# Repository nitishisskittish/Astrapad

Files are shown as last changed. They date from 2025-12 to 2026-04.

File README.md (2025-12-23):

## **Astrapad**
---
A 7 key macropad with a rotary encoder, OLED screen, and 16 WS2812B LED’s. Currently runs on KMK firmware

### **Features**
---
- Two Piece 3D Printable Case
- 128x32 OLED Display
- EC11 Rotary encoder
- 16 WS2812B RGB LEDs, probably waaayyy too much, but the more the merrier I guess
- 7 Keys

### **CAD Model**
---
The case is held together by 4 M3 Bolts and heatset inserts, 1 in each corner. The bottom half of the case has a built in tilt. Originally I designed this with see-through plastic “windows” in mind, but as of now those windows have been replaced with direct holes looking into the PCB. Maybe I’ll add them later.

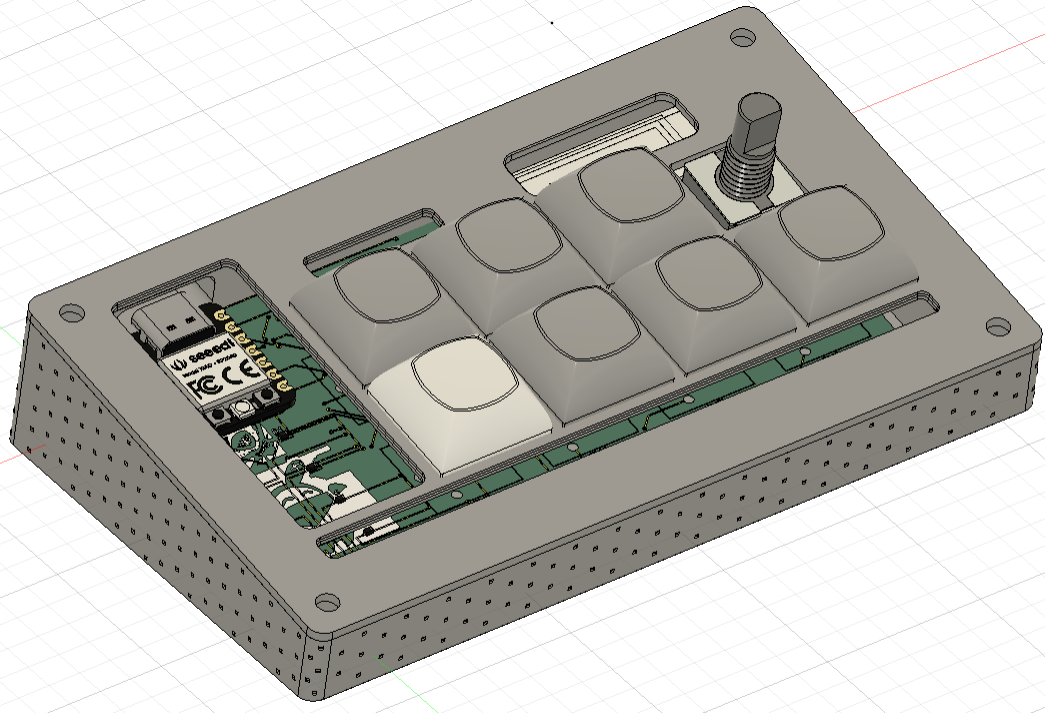
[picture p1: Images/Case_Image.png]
Case


### **PCB**
---
I made my PCB in KiCad. I got the bangboo silkscreen arts from the [Zenless Zone Zero Fandom Sticker Page](https://zenless-zone-zero.fandom.com/wiki/Stickers), and the pikachu art from [pixlecheese](https://www.pixilart.com/art/pikachu-thunderbolt-1a236168d6612c3)

- Schematic:

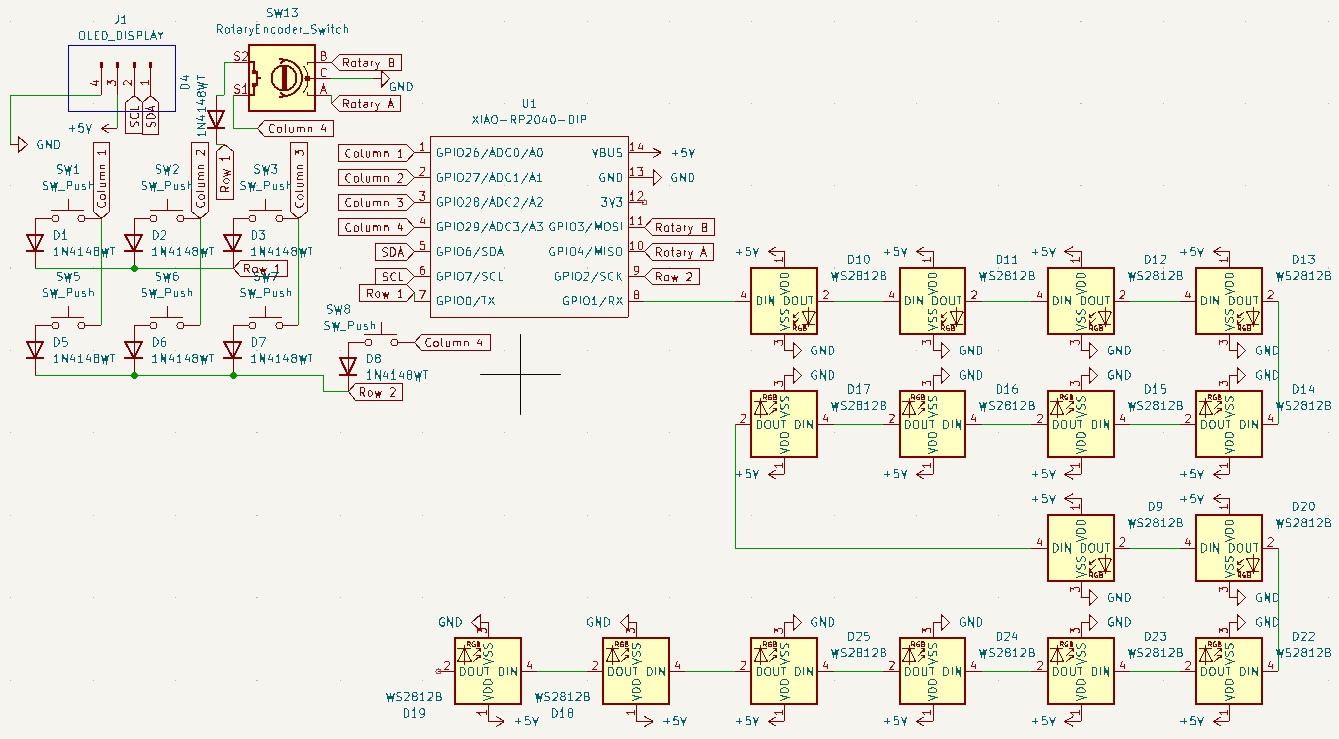
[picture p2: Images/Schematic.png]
Schematic
  
- Schematic:

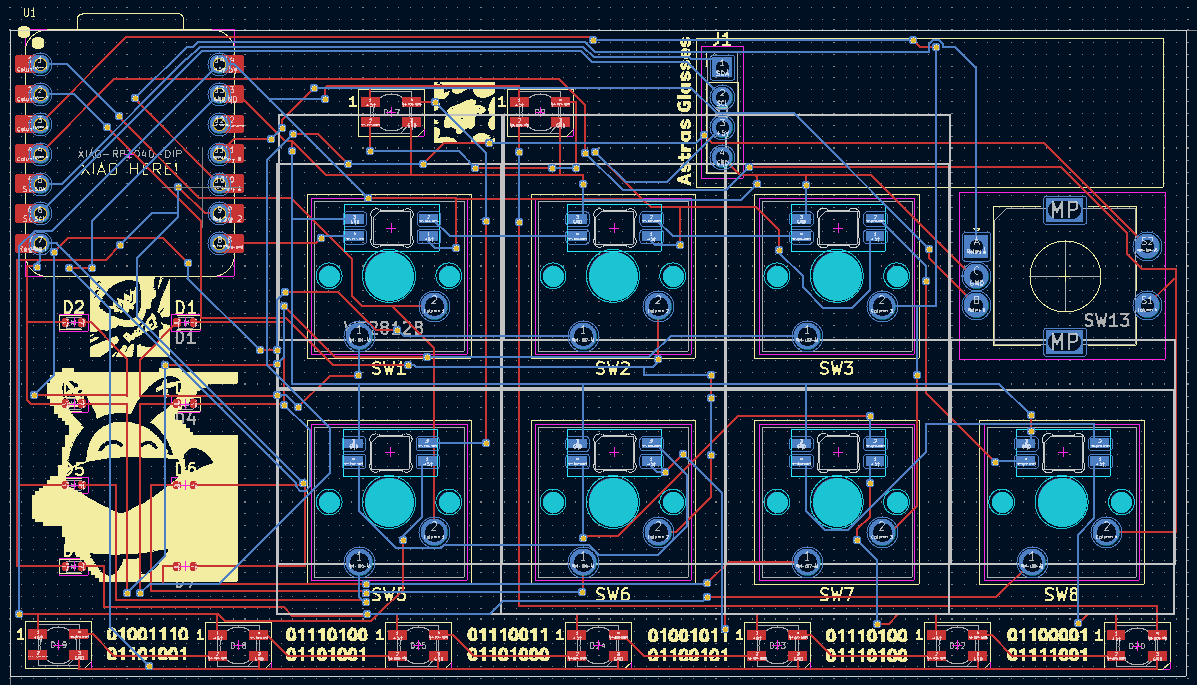
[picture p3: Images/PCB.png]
PCB
  
- My favorite part of the whole project tbh, made me feel very smart. Also if you're interested the numbers at the very bottom are binary, although it doesn’t spell out anything that interesting

### **Firmware**
---
Currently Astrapad runs on KMK, but I plan on switching to QMK later because I want to add [VIA](https://caniusevia.com/) support
- The rotary encoder changes the volume, and you can tap it to toggle mute
- The top left and top right keys skips forward or backward respectively in the playback queue
- The top middle button and bottom 3 buttons act as WASD keys, with the top middle button being the W Key
- The bottom right button is currently mapped to a custom shortcut I have on my computer that opens Spotify
- The OLED Screen displays the current volume level of whatever device the macropad is currently connected to
- I have a list of features I want to add commented in the KMK main.py file if you're interested in that
### **BOM**
---
- 1x Seeed XIAO RP2040
- 1x 0.91 inch OLED displays 
- 1x EC11 rotary encoders
- 1x Case (2 3D printed parts)
- 1x 3D printed EC11 (Rotary Encoder) Knob
- 4x M3x5x4 Heatset inserts
- 4x M3x16mm screws
- 7x Cherry MX Switches
- 7x DSA keycaps
- 8x Through-hole 1N4148 Diodes
- 16x SK6812 MINI-E LEDs

### **Extra Stuff**
---
The example I’m basing this README off of had this section, so I’m adding it too. 
Thanks a lot to the Blueprint Hackclub slack, I probably wouldn’t have finished this project without their help.
Ummm yeah, that’s it I guess.

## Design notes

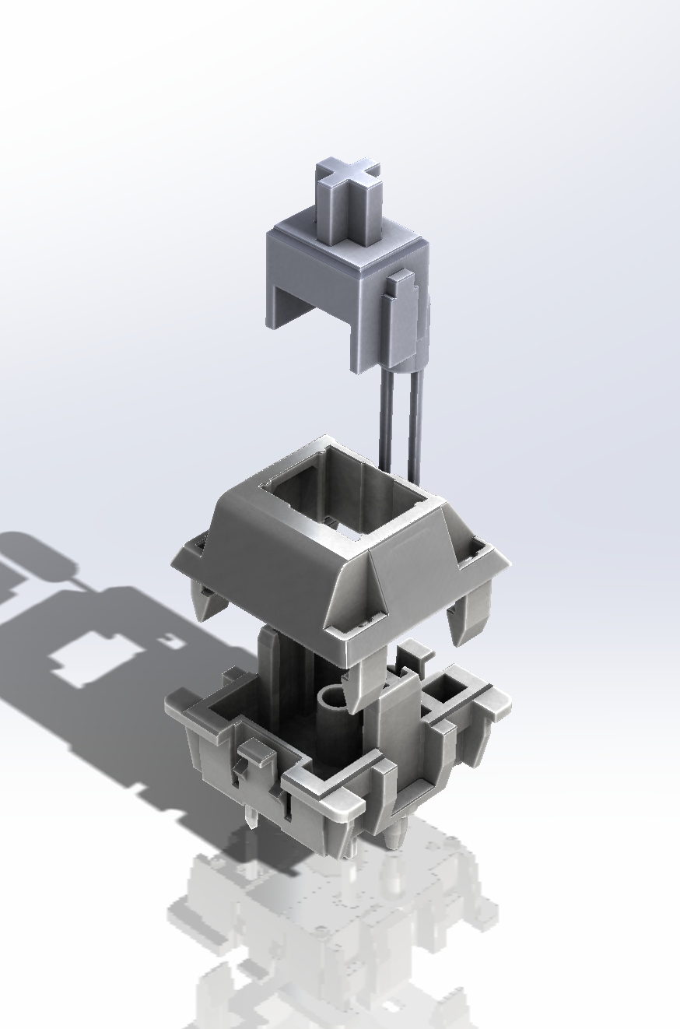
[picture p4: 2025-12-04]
KiCad (PCB)/3D Models/cherry-mx-switches-mx-1.snapshot.16/Renderings/屏幕截图(27)_副本.jpg

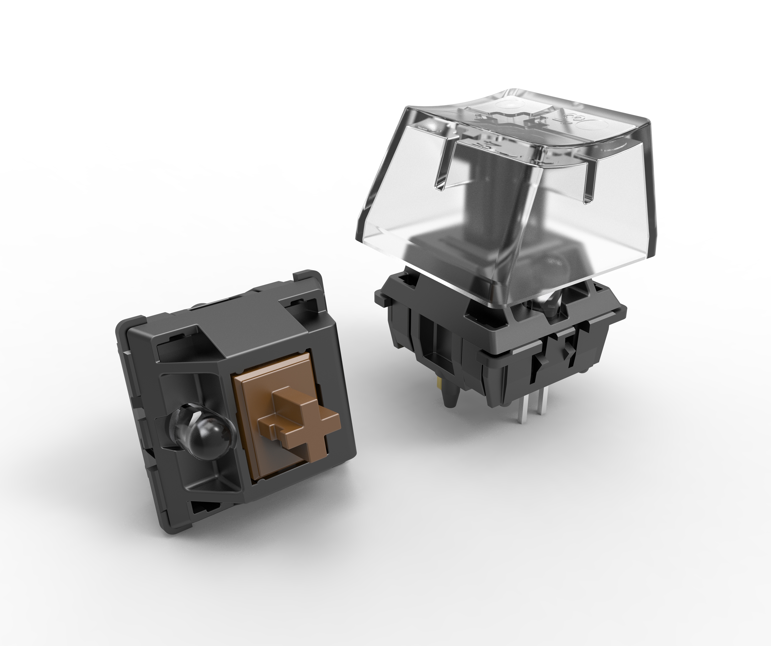
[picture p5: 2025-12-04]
KiCad (PCB)/3D Models/cherry-mx-switches-mx-1.snapshot.16/Renderings/untitled.199.jpg

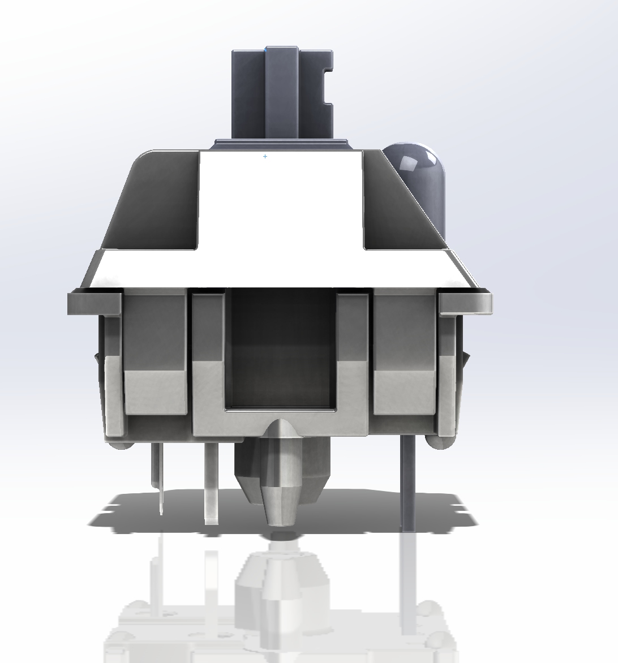
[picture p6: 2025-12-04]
KiCad (PCB)/3D Models/cherry-mx-switches-mx-1.snapshot.16/Renderings/屏幕截图(26).jpg

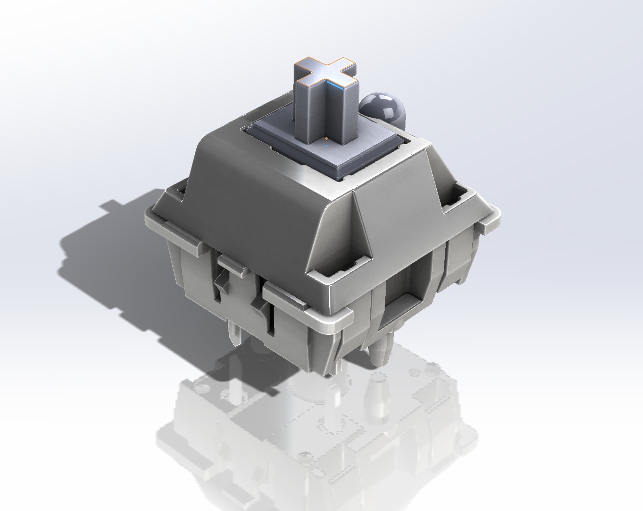
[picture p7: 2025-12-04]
KiCad (PCB)/3D Models/cherry-mx-switches-mx-1.snapshot.16/Renderings/屏幕截图(23).jpg

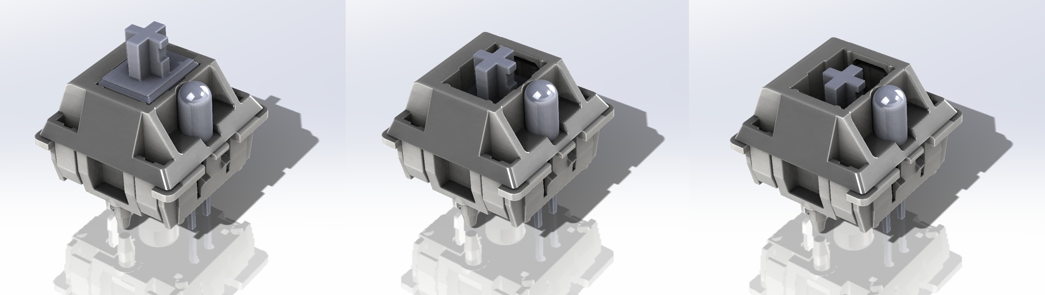
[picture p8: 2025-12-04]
KiCad (PCB)/3D Models/cherry-mx-switches-mx-1.snapshot.16/Renderings/屏幕截图(19).jpg

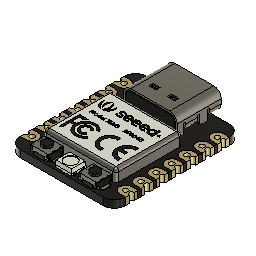
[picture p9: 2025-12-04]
KiCad (PCB)/3D Models/seeed-studio-xiao-rp2040-3d-model/Seeed Studio XIAO RP2040 v26/FusionAssetName[Active]/Previews/small.png

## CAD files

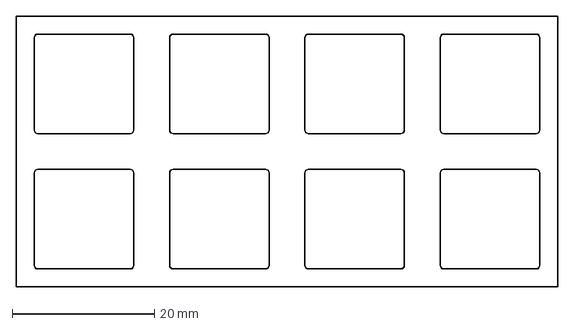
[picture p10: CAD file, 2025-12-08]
Fusion360 (CAD)/plate-2025-12-07T21_54_10.510Z.dxf
76.2 x 38.1 mm

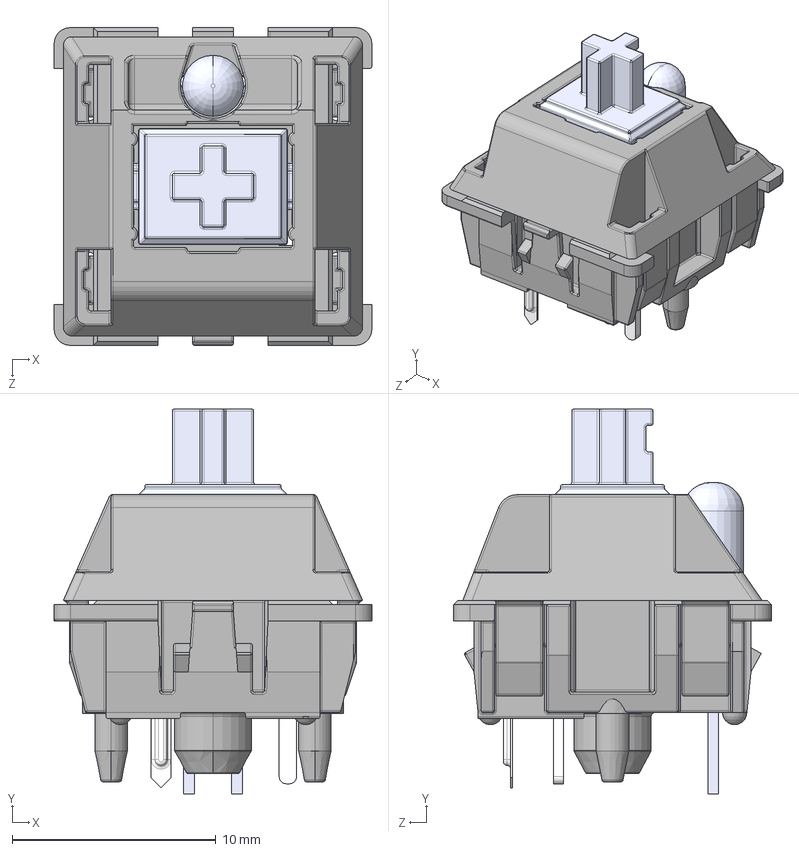
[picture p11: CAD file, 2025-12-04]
KiCad (PCB)/3D Models/cherry-mx-switches-mx-1.snapshot.16/MX .STEP
15.6 x 18.9 x 15.6 mm
MX 轴 按键′_ü___¨1
MX 轴 轴体áì_¨￠¨__
MX粣 拸簽LEDLEDLED
MX轴 轴体 底部 μ×2__默认_á2____è_
针脚___默认__è_

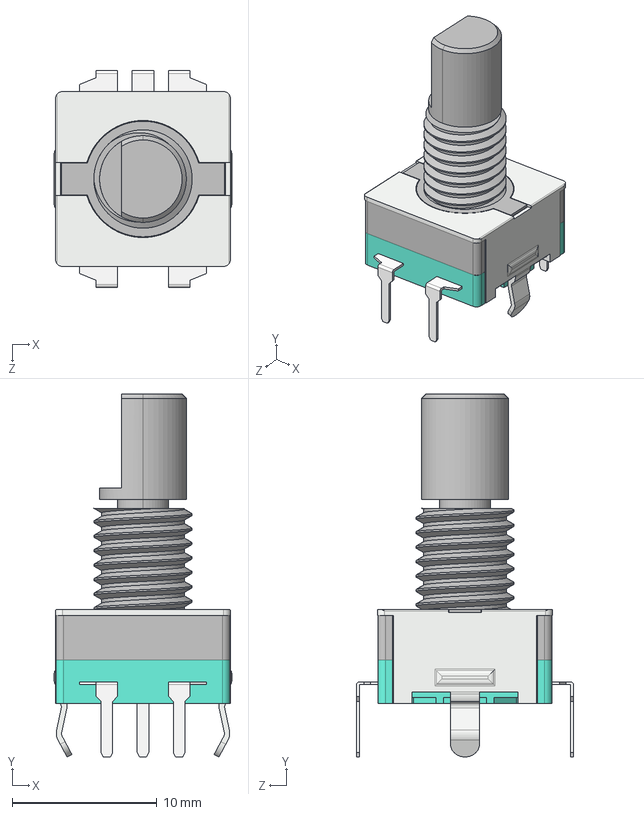
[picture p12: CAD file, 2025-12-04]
KiCad (PCB)/3D Models/rotary-encoder-17.snapshot.2/旋转编码器.STEP
12.3 x 25.1 x 15.0 mm

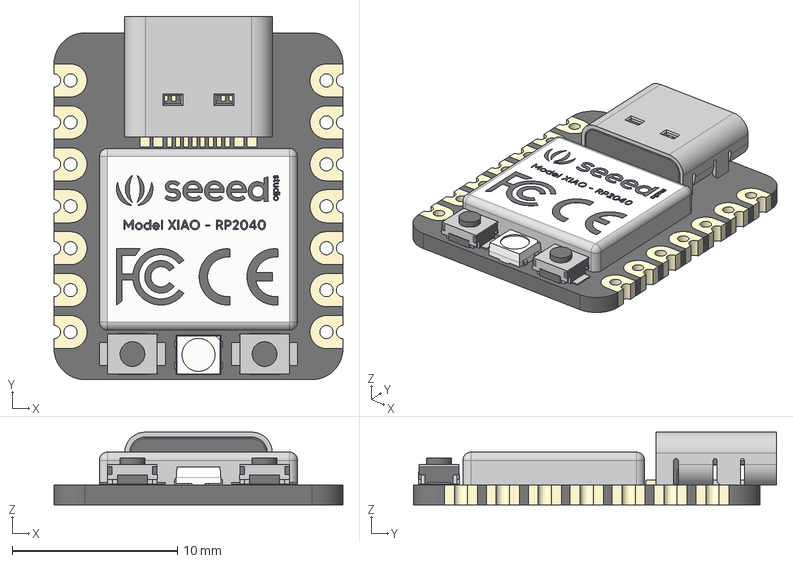
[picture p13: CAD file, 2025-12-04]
KiCad (PCB)/3D Models/seeed-studio-xiao-rp2040-3d-model/Seeed Studio XIAO RP2040 v26.step
17.5 x 22.0 x 4.40 mm
type-c v2
smd_button v3
DOUT
DIN
VSS
VDD
smd_button v3(Mirror)

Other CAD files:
FreeCAD/astrapad.FCStd
KiCad (PCB)/3D Models/rotary-encoder-17.snapshot.2/旋转编码器.SLDPRT

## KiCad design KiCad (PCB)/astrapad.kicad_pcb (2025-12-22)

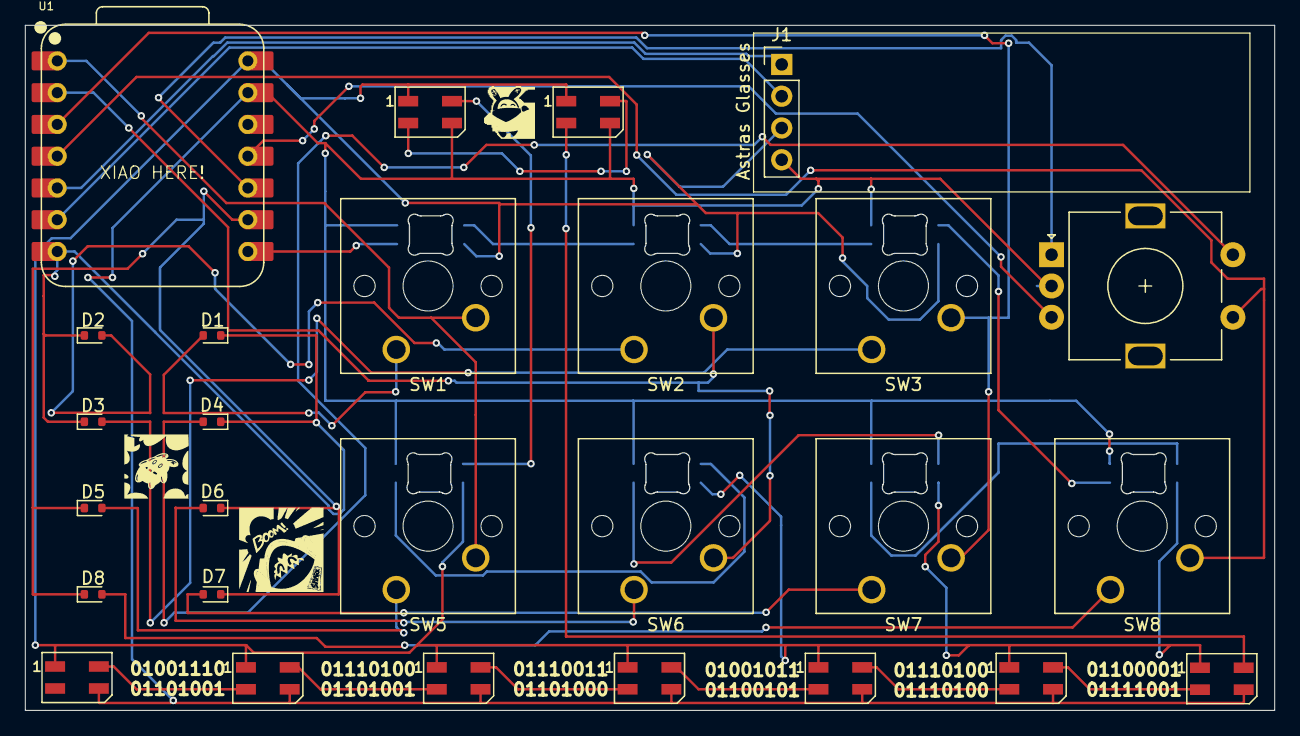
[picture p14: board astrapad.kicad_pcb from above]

Board: 2 copper layers, 99.9 x 54.8 mm, 34 parts (0 on the bottom side), 36 nets.

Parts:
D1, D2, D3, D4, D5, D6, D7, D8: 1N4148WT; D_SOD-523
D9, D17, D18, D19, D20, D22, D23, D24, D25: WS2812B; LED_SK6812MINI_PLCC4_3.5x3.5mm_P1.75mm
D10, D11, D12, D13, D14, D15, D16: WS2812B; MX_SK6812MINI-E_REV
J1: Astras Glasses; PinHeader_1x04_P2.54mm_Vertical
SW1, SW2, SW3, SW5, SW6, SW7, SW8: SW_Push; SW_Cherry_MX_1.00u_PCB
SW13: RotaryEncoder_Switch; RotaryEncoder_Alps_EC11E-Switch_Vertical_H20mm
U1: XIAO-RP2040-DIP

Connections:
+5V: D9.1 (VDD), D10.1 (VDD), D11.1 (VDD), D12.1 (VDD), D13.1 (VDD), D14.1 (VDD), D15.1 (VDD), D16.1 (VDD), D17.1 (VDD), D18.1 (VDD), D19.1 (VDD), D20.1 (VDD), D22.1 (VDD), D23.1 (VDD), D24.1 (VDD), D25.1 (VDD), J1.3, U1.14 (VBUS)
Column 1: SW1.2, SW5.2, U1.1 (GPIO26/ADC0/A0)
Column 2: SW2.2, SW6.2, U1.2 (GPIO27/ADC1/A1)
Column 3: SW3.2, SW7.2, U1.3 (GPIO28/ADC2/A2)
Column 4: SW8.2, SW13.S1, U1.4 (GPIO29/ADC3/A3)
GND: D9.3 (VSS), D10.3 (VSS), D11.3 (VSS), D12.3 (VSS), D13.3 (VSS), D14.3 (VSS), D15.3 (VSS), D16.3 (VSS), D17.3 (VSS), D18.3 (VSS), D19.3 (VSS), D20.3 (VSS), D22.3 (VSS), D23.3 (VSS), D24.3 (VSS), D25.3 (VSS), J1.4, SW13.C, U1.13 (GND)
unnamed: D1.2 (A), SW1.1
unnamed: D2.2 (A), SW2.1
unnamed: D3.2 (A), SW3.1
unnamed: D4.2 (A), SW13.S2
unnamed: D5.2 (A), SW5.1
unnamed: D6.2 (A), SW6.1
unnamed: D7.2 (A), SW7.1
unnamed: D8.2 (A), SW8.1
unnamed: D10.4 (DIN), U1.8 (GPIO1/RX)
unnamed: D10.2 (DOUT), D11.4 (DIN)
unnamed: D11.2 (DOUT), D12.4 (DIN)
unnamed: D12.2 (DOUT), D13.4 (DIN)
unnamed: D13.2 (DOUT), D14.4 (DIN)
unnamed: D14.2 (DOUT), D15.4 (DIN)
unnamed: D15.2 (DOUT), D16.4 (DIN)
unnamed: D16.2 (DOUT), D17.4 (DIN)
unnamed: D9.4 (DIN), D17.2 (DOUT)
unnamed: D18.4 (DIN), D25.2 (DOUT)
unnamed: D18.2 (DOUT), D19.4 (DIN)
unnamed: D9.2 (DOUT), D20.4 (DIN)
unnamed: D20.2 (DOUT), D22.4 (DIN)
unnamed: D22.2 (DOUT), D23.4 (DIN)
unnamed: D23.2 (DOUT), D24.4 (DIN)
unnamed: D24.2 (DOUT), D25.4 (DIN)
Rotary A: SW13.A, U1.10 (GPIO4/MISO)
Rotary B: SW13.B, U1.11 (GPIO3/MOSI)
Row 1: D1.1 (K), D2.1 (K), D3.1 (K), D4.1 (K), U1.7 (GPIO0/TX)
Row 2: D5.1 (K), D6.1 (K), D7.1 (K), D8.1 (K), U1.9 (GPIO2/SCK)
SCL: J1.2, U1.6 (GPIO7/SCL)
SDA: J1.1, U1.5 (GPIO6/SDA)

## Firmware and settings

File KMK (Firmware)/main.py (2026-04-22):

import board
import busio
import digitalio
import time
import adafruit_ssd1306
import usb_hid
import neopixel
from adafruit_hid.keyboard import Keyboard
from adafruit_hid.keycode import Keycode

pixels = neopixel.NeoPixel(board.D7, 17, brightness=1, auto_write=False)
colors = [
    (255, 0, 0),   # Red
    (0, 255, 0),   # Green
    (0, 0, 255),   # Blue
    (255, 255, 0), # Yellow
    (255, 0, 255), # Magenta
    (0, 255, 255)  # Cyan
]

def get_current_color(color_idx):
    colors_names = ["Red", "Green", "Blue", "Yellow", "Pink", "Cyan"]
    return colors_names[color_idx % 6]

color_idx = 0

pin_a = digitalio.DigitalInOut(board.D9)
pin_a.pull = digitalio.Pull.UP
pin_b = digitalio.DigitalInOut(board.D3)
pin_b.pull = digitalio.Pull.UP

col1 = digitalio.DigitalInOut(board.D0)
col1.direction = digitalio.Direction.OUTPUT
col1.value = False

row1 = digitalio.DigitalInOut(board.D6) # Button 1
row1.pull = digitalio.Pull.UP

row2 = digitalio.DigitalInOut(board.D8)
row2.pull = digitalio.Pull.UP

kbd = Keyboard(usb_hid.devices)
i2c = busio.I2C(board.D5, board.D4)
oled = adafruit_ssd1306.SSD1306_I2C(128, 32, i2c)

count = 0
last_a = pin_a.value

def update_display(msg, val):
    oled.fill(0)
    oled.text("ASTRAPAD", 0, 0, 1)
    oled.text("ACT:" + msg[:28], 0, 10, 1)
    oled.text("VAL:" + str(val), 0, 20, 1)
    oled.show()

pixels.fill(colors[color_idx])
pixels.show()
update_display("SYSTEM READY", count)

while True:
    cur_a = pin_a.value
    if cur_a != last_a:
        if pin_b.value != cur_a:
            count += 1
        else:
            count -= 1

        print(f"Count: {count}")
        update_display("SCROLLING", count)
        update_display("READY", count)
    last_a = cur_a

    if not row1.value:
        kbd.press(Keycode.SPACE)
        update_display("SPACE BAR", 0)
        kbd.release(Keycode.SPACE)
        time.sleep(0.15)
        update_display("READY", 0)

    if not row2.value:
        color_idx = (color_idx + 1) % len(colors)
        pixels.fill(colors[color_idx])
        pixels.show()
        update_display("COLOR CHANGED", get_current_color(color_idx))
        time.sleep(0.15)
        update_display("READY", count)

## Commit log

2025-11-28 Blueprint HackClub Macro Project - Initial Commit
    [Generalist_Macro.kicad_pcb, Generalist_Macro.kicad_sch]
2025-12-04 Renamed Project. Reorganized files. Cleaned up routing Struggled with importing 3D model of PCB with Components for hours on end. THE SEEED CONTROLLER STILL DOESNT SHOW UP IN 3D VIEW. gave up. I WILL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
    [Generalist_Macro-B_Cu.gbr, Generalist_Macro-B_Mask.gbr, Generalist_Macro-B_Paste.gbr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]
2025-12-07 Resized PCB to fit 100mmx100mm limit Turns out the PCB has a max size of 100mmx100mm, mine was 106x59. I resized it though so we good now
    [astrapad.kicad_pcb, astrapad.kicad_sch]
2025-12-08 Finished Firmware
    [astrapad.kicad_pcb, plate-2025-12-07T21_54_10.510Z.dxf]
2025-12-20 Syncing PCB 3D Model
2025-12-22 Added some silkscreens
    [astrapad.kicad_pcb]
2025-12-22 Didn't update 3D Model paths after changing file organization
    [astrapad.kicad_pcb]
2025-12-23 PCB image in readme had wrong silkscreens
2025-12-23 Added Pikachu silkscreen art to pcb, exported Gerber files
    [astrapad-B_Cu.gbl, astrapad-B_Mask.gbs, astrapad-B_Paste.gbp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]
2026-04-09 So...it's been a while A lot of things went wrong with assembly, just to name a few: The 3D printed case was to tight, and the pcb didn't fit inside The upwards facing LED's were impossible to solder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
    Until now,
    With this new firmware the macropad now works. Buttons (well only one right now, haven't given the rest a function), rotary dial, the screen, the LEDs backlighting the keys, all of it.
    It did take me a while to find time, but I think I can now say that this project wasn't a complete fai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
    [main.py]
